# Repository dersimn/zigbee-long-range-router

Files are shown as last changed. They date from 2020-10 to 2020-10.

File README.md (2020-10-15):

# CC2530+CC2592 Long Range ZigBee Router
Mod of cod.m's [Zigbee Long Range Router](https://shop.codm.de/automation/zigbee/23/zigbee-cc2530-cc2592-long-range-router/repeater) based on EByte's [E18-MS1PA2-PCB](http://www.ebyte.com/en/product-view-news.aspx?id=988) sporting an CC2530 combined with an CC2592 PA/LNA for range extension.

The corresponding eagle library for the EByte modules, including 3D models, can be found here: https://github.com/codm/eagle-libraries

You can buy a ready built router, including external antenna, 3D printed case and power supply at our webshop: [CC2530-CC2592 Long Range ZigBee Router](https://shop.codm.de/automation/zigbee/23/zigbee-cc2530-cc2592-long-range-router/repeater)

# Firmware
Thanks to https://ptvo.info and his [configurable ZigBee Firmware](https://ptvo.info/zigbee-switch-configurable-firmware-v2-210/), we've built our own version of the firmware - based on Z-Stack 1.2 - to make use of the onboard LED.

See zigbee2mqtt's FAQ for more info on how to use ZigBee routers and expand your current ZigBee mesh: https://www.zigbee2mqtt.io/information/FAQ.html#i-read-that-zigbee2mqtt-has-a-limit-of-20-devices-is-this-true

## Upgrading
You can flash the module with a another/new firmware using an CC-Debugger from TI, which is also used for the common CC2531-USB-Sticks. The pin header on the top has the same layout.

# License
[CC-BY-SA-NC 3.0](https://creativecommons.org/licenses/by-nc-sa/3.0/de/)

Credits:
- cod.m GmbH, Patrik Mayer, 2020
- [Simon Christmann](https://github.com/dersimn), 2020

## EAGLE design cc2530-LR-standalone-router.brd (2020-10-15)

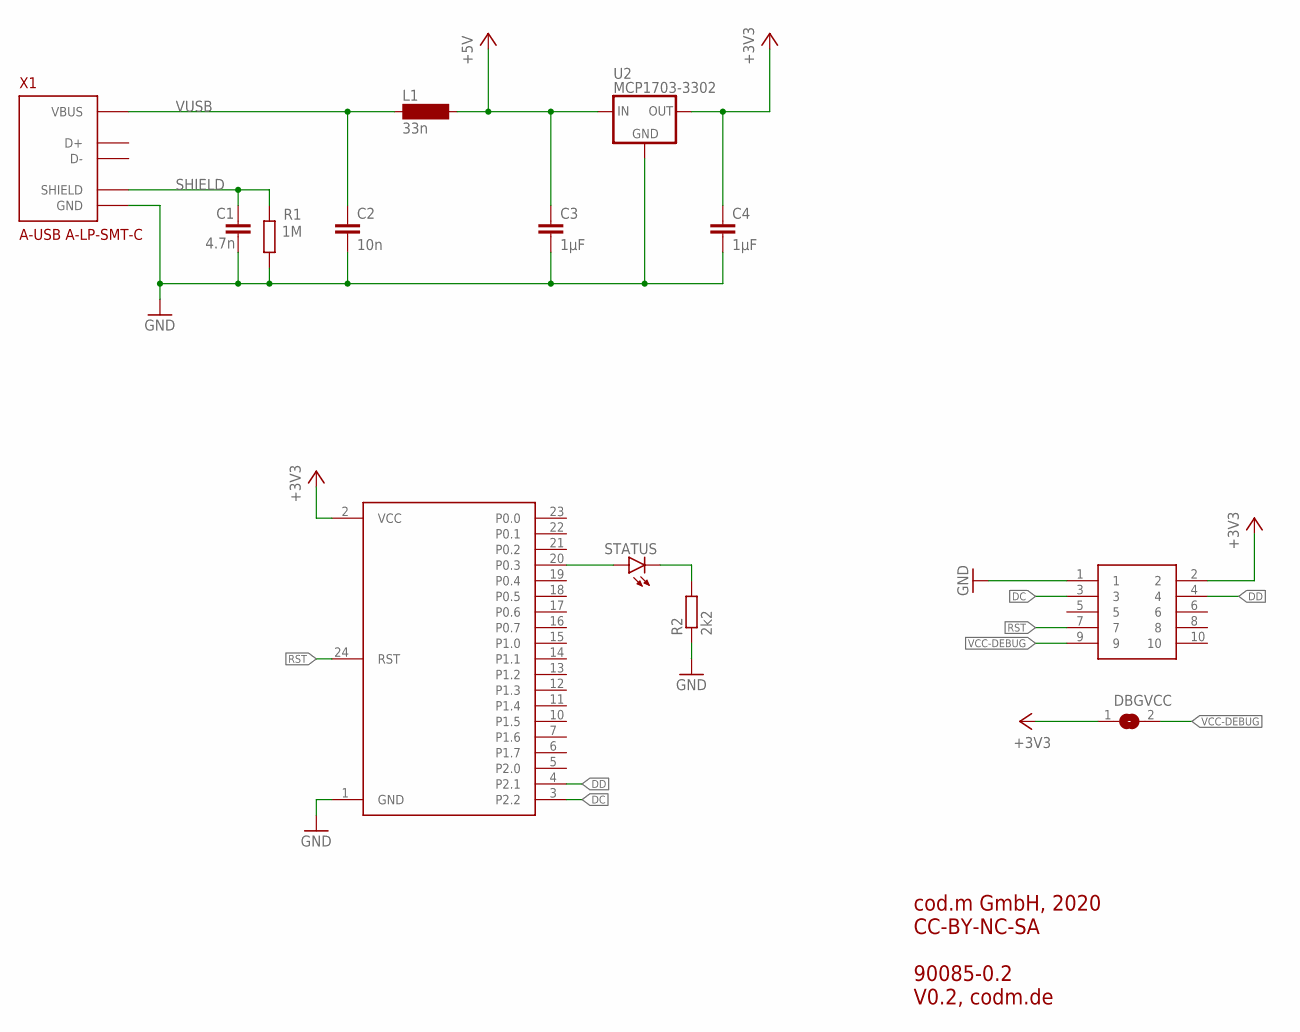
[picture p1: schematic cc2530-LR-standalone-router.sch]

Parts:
C1: 4.7n; C1206
C2: 10n; C1206
C3, C4: 1µF; C1206
DBGVCC: SJ
DEBUG: 20021121-00010C4LF; 2002112100010C4LF
L1: 33n; SM-1206
R1: 1M; R1206
R2: 2k2; R1206
STATUS: LEDCHIPLED_1206; CHIPLED_1206
U2: MCP1703-3302; SOT-22-3
U$5: E18-MS1PA2-PCB
X1: A-USB A-LP-SMT-C; A-USB_A-LP-SMT-C

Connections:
+3V3: C4.1, DBGVCC.1, DEBUG.2, U2.3 (OUT), U$5.2 (VCC)
+5V: C3.1, L1.2, U2.1 (IN)
DC: DEBUG.3, U$5.3 (P2.2)
DD: DEBUG.4, U$5.4 (P2.1)
GND: C1.2, C2.2, C3.2, C4.2, DEBUG.1, R1.2, R2.1, U2.2 (GND), U2.4 (GND), U$5.1 (GND), X1.4 (GND)
unnamed: R2.2, STATUS.C
unnamed: STATUS.A, U$5.20 (P0.3)
RST: DEBUG.7, U$5.24 (RST)
SHIELD: C1.1, R1.1, X1.S1 (SHIELD), X1.S2 (SHIELD)
VCC-DEBUG: DBGVCC.2, DEBUG.9
VUSB: C2.1, L1.1, X1.1 (VBUS)

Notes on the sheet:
cod.m GmbH, 2020 CC-BY-NC-SA 90085-0.2 V0.2, codm.de

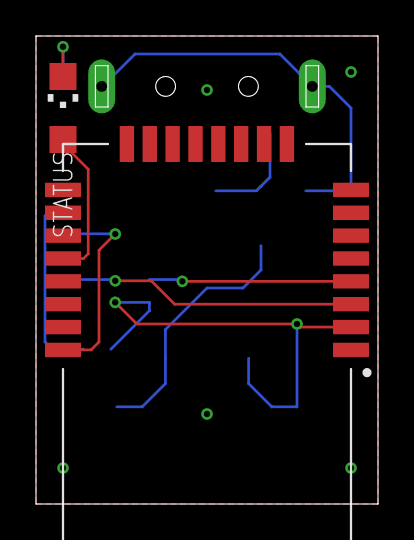
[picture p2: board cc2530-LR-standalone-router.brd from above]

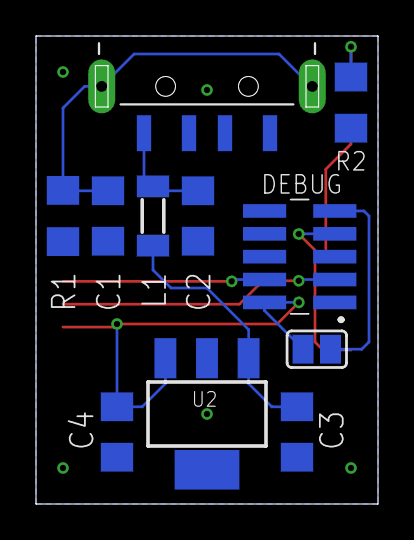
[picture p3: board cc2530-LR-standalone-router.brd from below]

Board: 2 copper layers, 19.0 x 26.0 mm, 13 parts (11 on the bottom side), 11 nets.
